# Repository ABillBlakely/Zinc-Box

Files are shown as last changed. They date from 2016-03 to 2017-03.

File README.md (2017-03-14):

# The Zinc Box

### The feature complete RIAA preamp.
#### A Cal Poly AES club project.

## Introduction.

The Zinc Box is an RIAA phono preamp meant to be a simple, high performance preamp for my personal use. The V1.0 was developed solely by myself and was lacking in some of the performance metrics. A new version is being developed within the CPSLO AES club to improve the features and performance of the Zinc Box.

In this repository you will find:
- KiCad contains the project files for schematic capture and PCB creation. In this folder you will also find the Gerber files used for PCB production.
- LTspice folder contains the files used for simulation and testing of project designs.
- Main directory has the current schematic, some reports, and this readme.

## Performance of V1
V1 offered up some pretty decent performance, but has its issues as well. For a more thorough look at performance, check [Performance V1.0.md](Performance V1.0.md).

- Freq Response within +/- 2 dB of ideal across the audio spectrum.
- Channel matching within +/- 0.25 dB.
- THD < 0.05%
- IMD < 0.08%

## Goals
For the second version, subject to change as project is established:
- Match ideal freq response to +/- 0.1dB.
- Lower power supply noise (120 Hz < -90 dB).
- Greatly improved enclosure design, appearance.
- Adjustable input loading.
- THD < 0.005% @ 1 kHz, -3dB output level.
- THD+N < 0.05% @ 1kHz, -3dB output level.
- IMD < 0.05% ITU-R, 13 + 14 kHz 1:1 ratio.

## Updates

#### 2017-3-24 Meeting
We discussed power supply design, and probably tried to cover too many topics in not enough depth. The quick recap:

- The objective of a power supply is to provide stable, constant voltage at the right voltage for the circuit. We know our circuit consists of two op amps so we can figure that we need positive and negative supplies, a total voltage of 20 to 30 volts, and current requirements in the 10's of mA.
- Ripple is the AC noise present on what should be a clean DC supply. V1.0 of the project has problems with power supply noise, so reducing this is a priority.
- An AC voltage must be rectified. The two main types are half-wave and full wave rectification. Full wave wave doubles the ripple frequency while reducing the ripple voltage (both good things) at the expense of requiring 4x the parts count of half wave (or a dedicated IC). 
- An RC filter can reduce ripple, but current will cause a voltage drop across the resistor, and at some point capacitors become physically large and/or expensive, and this limits how effective the filter can be.
- Linear regulators are cheap and easy ways to get a specific voltage output. They come in fixed and variable forms, and usually have around 60 dB (thats a reduction by a factor of 1000) of ripple rejection. 

I am asking that you download the LTSpice folder from up above and install [LTSpice](http://www.linear.com/designtools/software/#LTspice). Ive set up a starting point in 'power supply.asc' from which I would like you to adjust C1, C2, and R1 and try to find a combination that keeps ripple less than 30 uV peak to peak. If you have trouble running the sim, make sure that the two MC78XX files are in the same directory as 'power supply.asc'.

When you have some values that work, go on digikey, mouser or similar and see if you can find the parts available at a reasonable cost. Caps will likely need to be Aluminum electrolytic and should be rated for 50V or higher. 

You may wish to modify the circuit for full wave rectification or make other improvements, any and all improvements are welcome, you can also try simulating a negative regulator using the MC7915. I've added some resources down below specific to power supplies. 

The next official meeting will be the first week of the spring quarter, so there is no rush to get this done during finals week. Questions are welcome in the GroupMe, and let me know if you need to be added to that.

#### Upcoming Meeting 2017-3-10
The next meeting of the Zinc Box preamp project will be Friday, March 10 at 3:00 in the controls lab (20-112).

For this meeting we will be discussing power supply requirements and the basics of power supply design. This meeting will transition out of the workshop style of th first meeting and into having you all doing the hands on design work.

#### 2017-2-24 Meeting
The first meeting held established some of the background of audio testing and measurement.

- I highly recommend you get [ARTA](http://artalabs.hr/), the user manual is pretty good at guiding you through the setup and measurement techniques.
- [Audio Specifications](http://www.rane.com/note145.html) from Rane Audio is a great, succinct, resource for some more detail on the measurements we performed. It also may give you ideas for additional measurements we should make.
- We established some of the goals which are updated in the __Goals__ section above.
- (UPDATE: In room 126.) Next meeting will be Thursday, March 2. We will be performing measurements a little more methodically to produce a new performance report.

## References and Resources
- [LM317]() is a common adjustable regulator, this datasheet has lots of example circuits and aplications worth looking at.
- [MC78XX](http://www.onsemi.com/pub/Collateral/MC7800-D.PDF) is a common fixed positive voltage regulator, the MC79XX are the associated negative voltage regulators.
- [Small, Low Current Power Supplies](http://sound.whsites.net/articles/power-supplies2.htm) from Elliot sound products. This is the second time I've linked to this site, there is lots of good info and example projects here.
- [App note 140, Basic Concepts of Linear Regulator and Switching
Mode Power Supplies](http://cds.linear.com/docs/en/application-note/AN140fa.pdf) from Linear Technology covers some info on when to use linear regulator vs a switching regulator.

- [RIAA Equalization](https://en.wikipedia.org/wiki/RIAA_equalization) from wikipedia for what the RIAA curve is and the history behind the standard.
- [Audio Specifications](http://www.rane.com/note145.html) from Rane Audio for the what and why of audio measurements.
- [ARTA](http://artalabs.hr/) for performing measurements.
- [High-Performance Audio Applications of the LM833](http://www.ti.com/lit/an/snoa586d/snoa586d.pdf) from Texas instruments will be a major reference for design of the filter.
- [Magnetic Phono Pickup Cartridges](http://sound.whsites.net/articles/cartridge-loading.html) from Elliot Sound Products, a discussion on input loading for phono preamps.

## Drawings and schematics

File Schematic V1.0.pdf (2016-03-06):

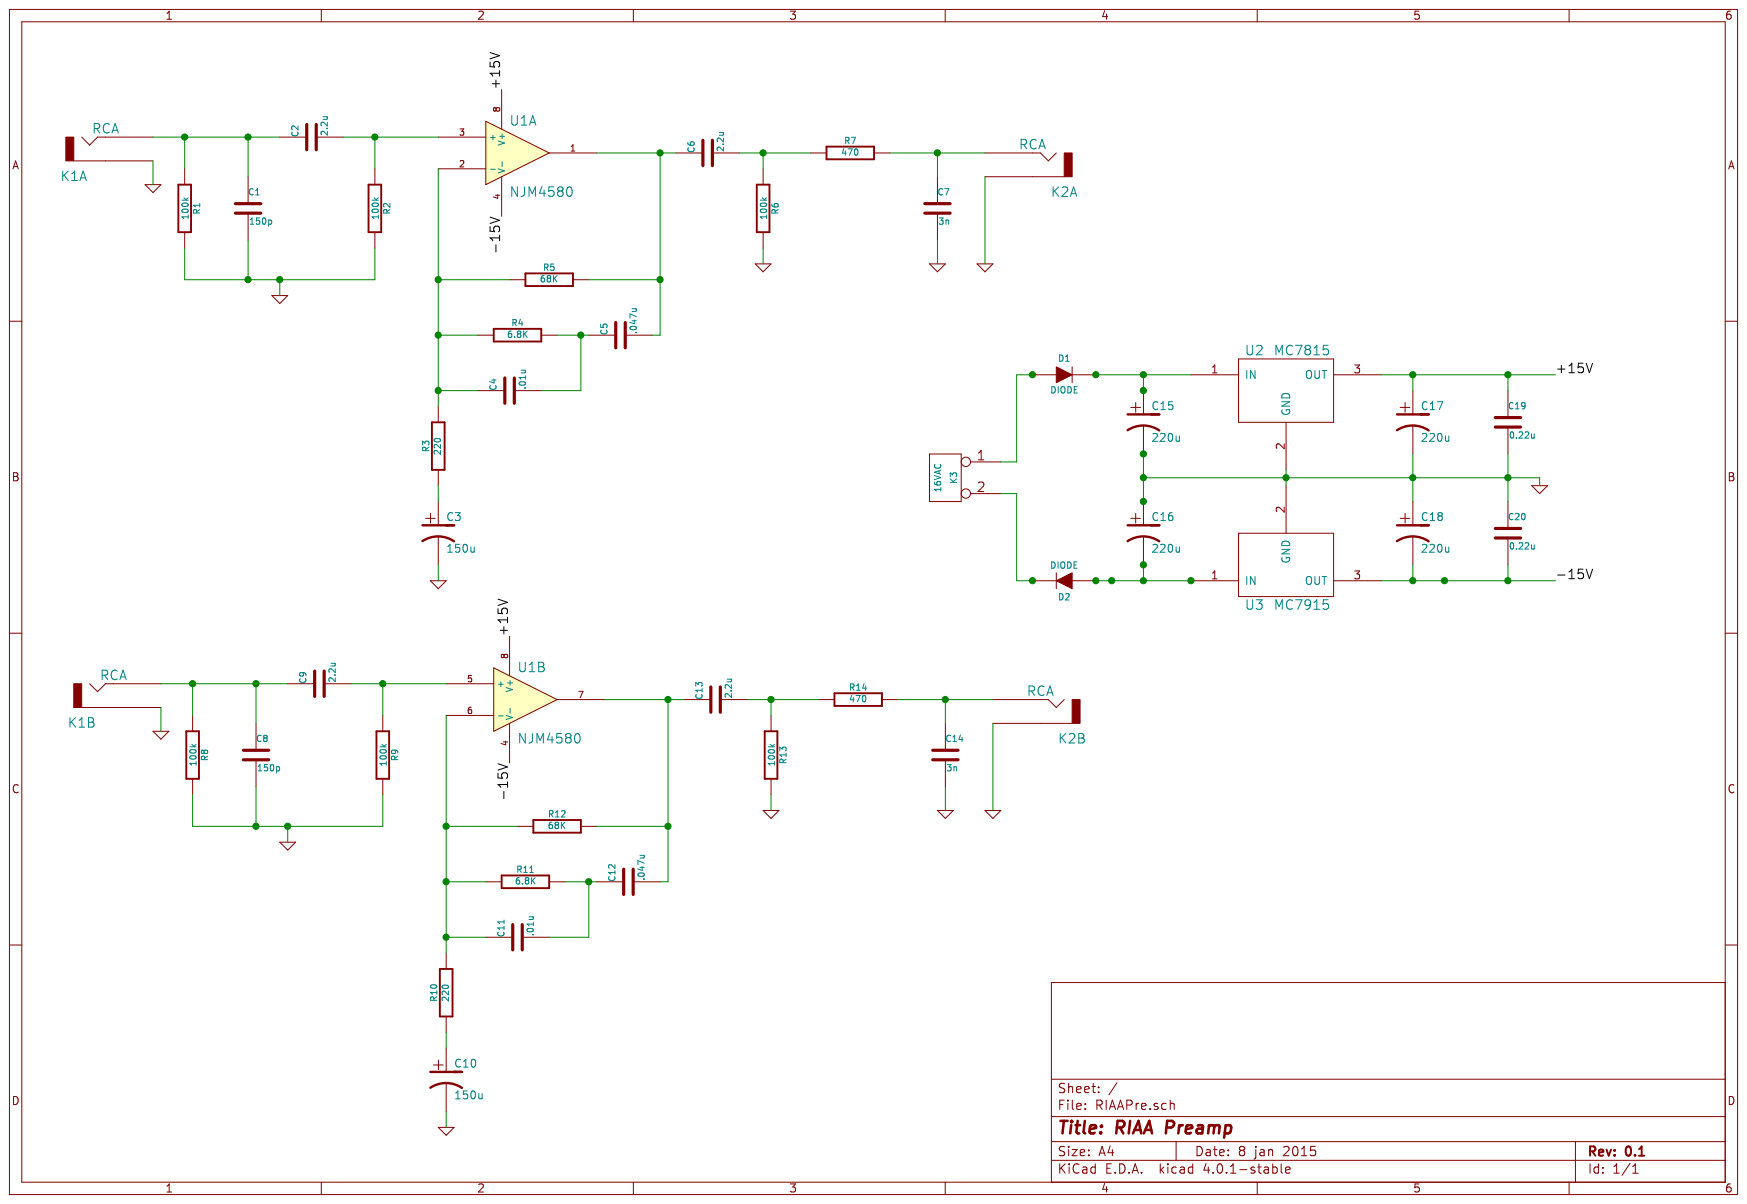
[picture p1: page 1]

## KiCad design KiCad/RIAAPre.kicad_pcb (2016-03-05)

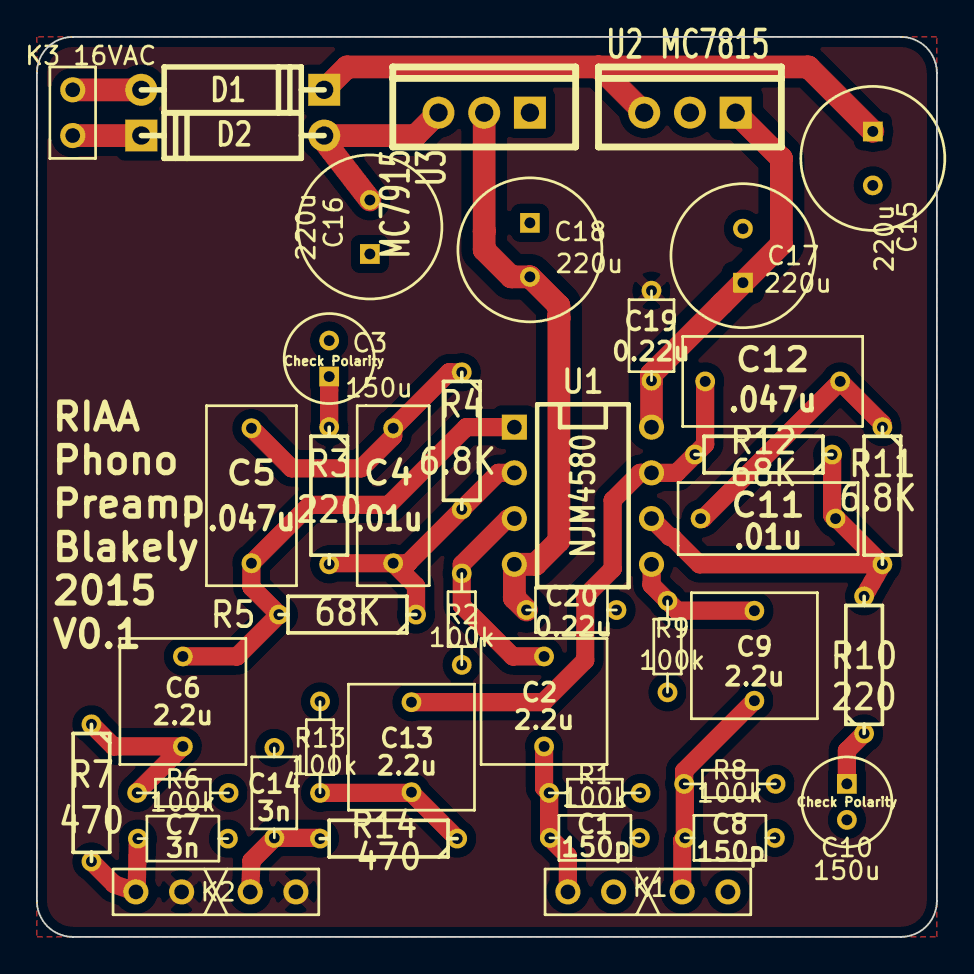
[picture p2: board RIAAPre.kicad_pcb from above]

Board: 2 copper layers, 50.0 x 50.0 mm, 42 parts (0 on the bottom side), 23 nets.

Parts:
C1, C8: 150p; Cap_4.0x2.5_5.0x0.55
C2, C6, C9, C13: 2.2u; Cap_7.2x7.2_5.0x0.55
C3, C10: 150u; Cap_elec_5.0D_2.0x0.55
C4, C11: .01u; Cap_10x4_7.5x0.5
C5, C12: .047u; Cap_10x5.0_7.5x0.5
C7, C14: 3n; Cap_4.0x2.5_5.0x0.55
C15, C16, C17, C18: 220u; Cap_elec_8.0D_3.5x0.55
C19, C20: 0.22u; Cap_4.0x2.5_5.0x0.55
D1, D2: DIODE; D4
K1, K2: RCA; header4_gap
K3: 16VAC; header2
R1, R2, R6, R8, R9, R13: 100k; R_3.0x1.5_5.0x0.55
R3, R10: 220; R_6.5x2.0_7.5x0.55
R4, R11: 6.8K; R_6.5x2.0_7.5x0.55
R5, R12: 68K; R_6.5x2.0_7.5x0.55
R7, R14: 470; R_6.5x2.0_7.5x0.55
U1: NJM4580; DIP-8__300
U2: MC7815; TO220_VERT
U3: MC7915; TO220_VERT

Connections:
/+15V: C17.1, C19.1, U1.8, U2.3
/-15V: C18.2, C20.2, U1.4, U3.2
GND: C1.2, C3.2, C7.2, C8.2, C10.2, C14.2, C15.2, C16.1, C17.2, C18.1, C19.2, C20.1, K1.2, K1.4, K2.2, K2.4, R1.2, R2.2, R6.2, R8.2, R9.2, R13.2, U2.2
unnamed: C1.1, C2.1, K1.1, R1.1
unnamed: C3.1, R3.1
unnamed: C10.1, R10.1
unnamed: C6.2, R6.1, R7.1
unnamed: C12.2, C13.1, R12.2, U1.7
unnamed: C4.2, C5.1, R4.1
unnamed: C7.1, K2.1, R7.2
unnamed: C5.2, C6.1, R5.2, U1.1
unnamed: C4.1, R3.2, R4.2, R5.1, U1.2
unnamed: C2.2, R2.1, U1.3
unnamed: C16.2, D2.1, U3.1
unnamed: C15.1, D1.2, U2.1
unnamed: D2.2, K3.2
unnamed: C8.1, C9.1, K1.3, R8.1
unnamed: C11.2, C12.1, R11.1
unnamed: C11.1, R10.2, R11.2, R12.1, U1.6
unnamed: C13.2, R13.1, R14.1
unnamed: D1.1, K3.1
unnamed: C14.1, K2.3, R14.2
unnamed: C9.2, R9.1, U1.5

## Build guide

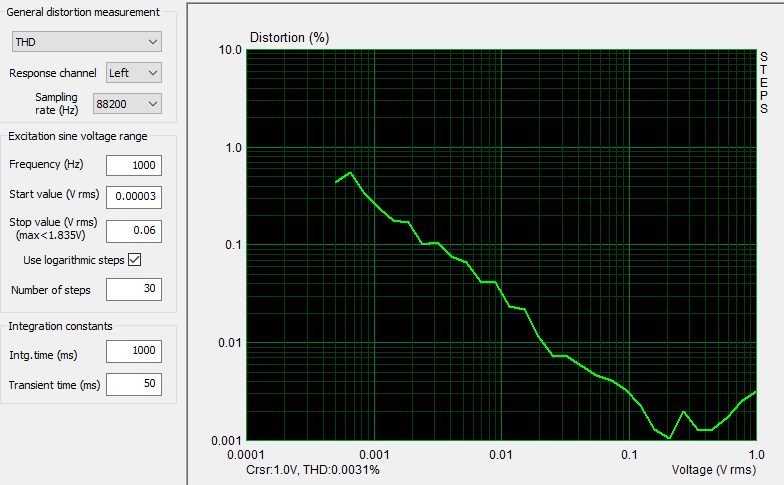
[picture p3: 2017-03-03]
Performance/figures/steps_thd_vs_amplitude.PNG

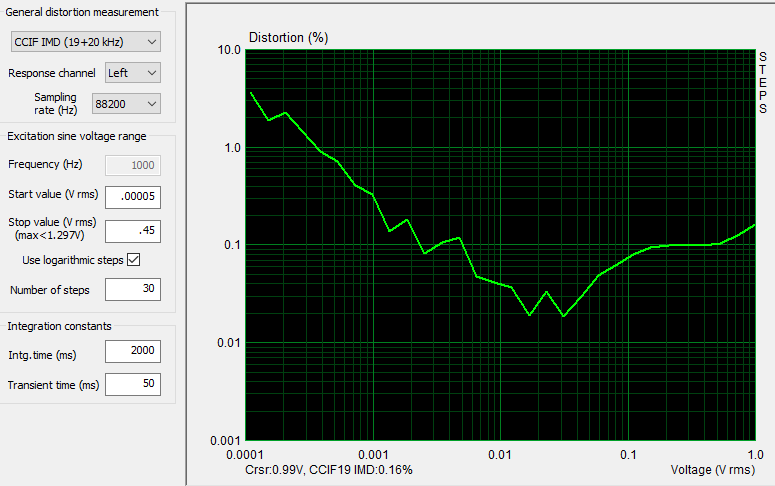
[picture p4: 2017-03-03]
Performance/figures/steps_IMD_vs_amplitude.PNG

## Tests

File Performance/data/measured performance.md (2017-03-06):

# Recorded data from 2017-3-1

## Conditions
88.2 kHz sample rate, 16384 samples, kaiser 7 window, using 100 averages

## Distortion

| Freq (Hz) | Level (dB) | THD (%) | THD+N (%) |
|---|---|---|---|
| 100 | -3.0 |  0.0099 | 0.055 |
| 1000 | -3.3 |  0.0034 | 0.067 |
| 10000 | -2.9 | 0.025 | 0.073 |

| Freqs  (kHz) | Level (dB) | Magnitude ratio | IMD (%) | standard |
|---|---|---|---|---|
| 19/20 | -3.0 | 1:1 | 0.062 | ITU-R |

## Noise

SNR = -67.0 dB re 0 dB, 44 kHz BW.

The noise figure is dominated by the power line noise, with a peak at 60 Hz of -68.54 dB.
No additional filter was used to limit bandwidth, but the low signal level causes the noise above 20 kHz to be negligible, so the value does not significantly improve by limiting bandwidth.

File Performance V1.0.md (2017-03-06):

# RIAA Phono Preamp
## V1.0 Characteristics and Performance.
To characterize the performance of the preamp tests were performed using the [ARTA](http://www.artalabs.hr/) software package. This summary of results is divided into frequency response and distortion.

## Frequency Response.
The frequency response was measured using ARTA, and the data was compared against the ideal response and against an LTSpice simulation of the signal chain. A comparison between the right and left channel was also performed. All values were normalized at 1 kHz to make comparison consistent.

### Overall Response.
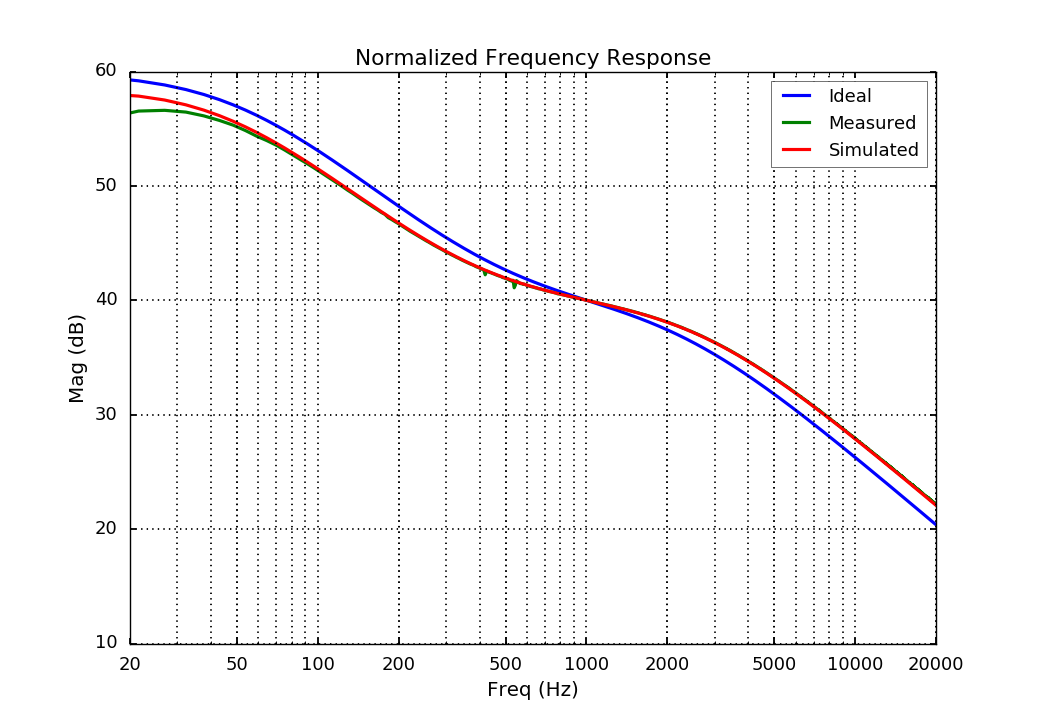
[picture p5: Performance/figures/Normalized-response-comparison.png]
Frequency Response

*Figure 1: Results of frequency measurement.*

The measured response matches the LTspice simulation so closely that it's data is almost obscured entirely. There is some obvious error when compared with the ideal response. This is one of the goals of version 2. Knowing that the simulation can be trusted to match closely with real world performance should make the job of choosing better component values easier.

### Response Error.
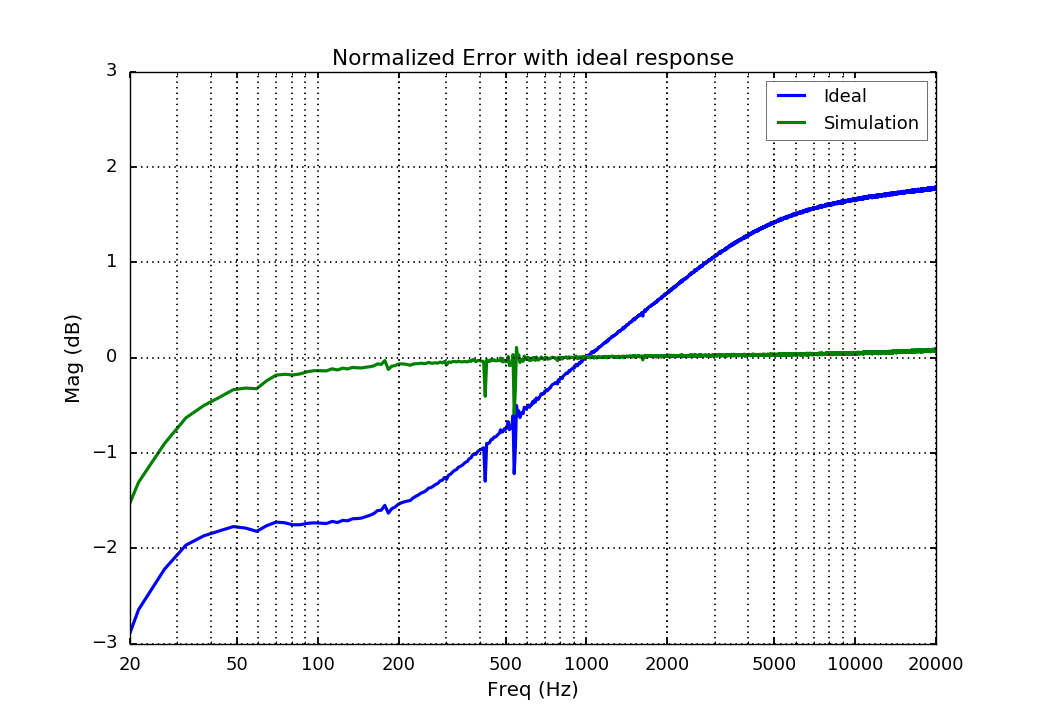
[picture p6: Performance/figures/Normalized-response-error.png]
Frequency Error

*Figure 2: Relative frequency response.*

Figure 2 shows the difference from the measured response to simulated (blue) and the ideal (red). This graph also quantifies what figure 1 had shown before. less than 0.5 dB difference from 20 Hz to 20 kHz for the simulation is very good. The ideal response is not so good, at around 1.5 db too low at low frequencies and almost 2 dB high at high frequencies. This is almost certainly audible difference.

### Channel Matching.
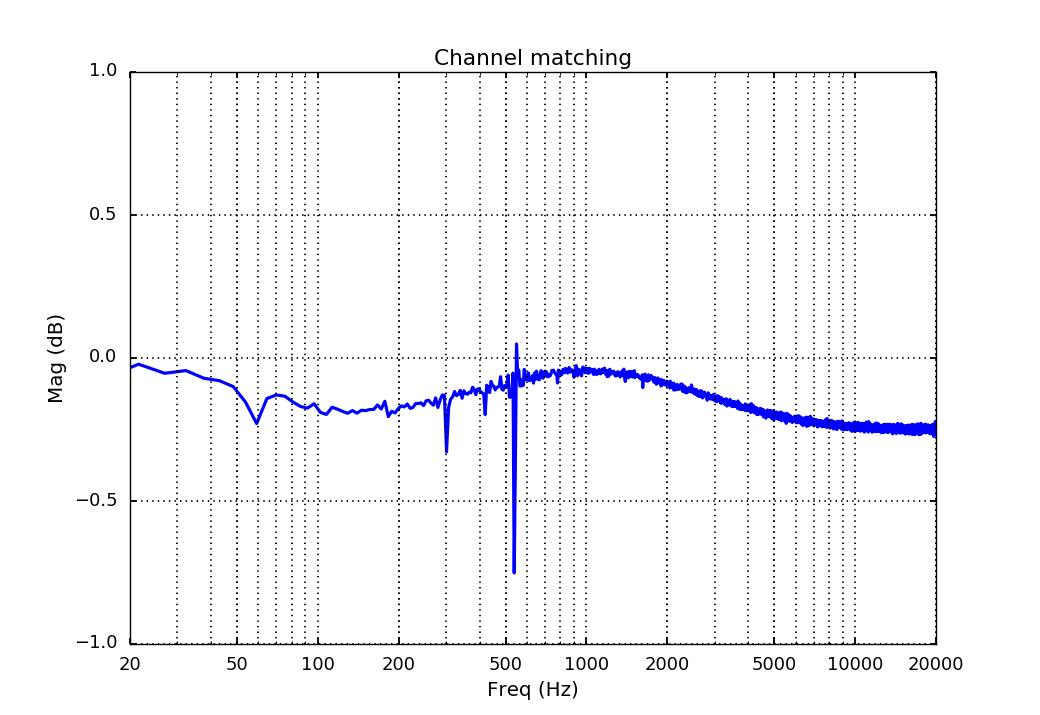
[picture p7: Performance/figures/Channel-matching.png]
Channel Matching

*Figure 3: Difference between left and right channels.*

## Distortion.
Three types of distortion were measured for these tests. THD (*Total harmonic distortion*), THD+N (*THD plus noise*), and IMD (*intermodulation distortion*). THD was checked for anomalies using steps to measure across the frequency response as seen in Figure 4. Measured values are taken at specific points to measure relative to correct signal levels. IMD uses the ITU_R standard of 19/20 kHz twin tones at a ratio of 1:1. For more information on audio distortion I recommend starting with [This RANE Audio note](http://www.rane.com/note145.html).

### Harmonic Distortion.

| Freq (Hz) | Level (dB) | THD (%) | THD+N (%) |
|---|---|---|---|
| 100 | -3.0 |  0.0099 | 0.055 |
| 1000 | -3.3 |  0.0034 | 0.067 |
| 10000 | -2.9 | 0.025 | 0.073 |

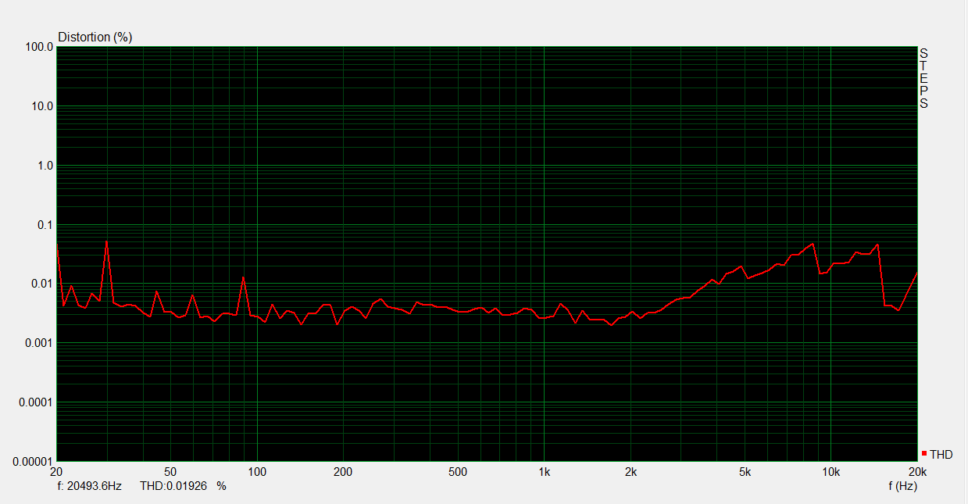
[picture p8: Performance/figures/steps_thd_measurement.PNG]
THD

*Figure 4: THD measured across frequency. Due to the non flat frequency response this does not use the preferred -3dB  signal level so final measurements are performed at just a few values.*

### Intermodulation Distortion.

| Freqs  (kHz) | Level (dB) | Magnitude ratio | IMD (%) | standard |
|---|---|---|---|---|
| 19/20 | -3.0 | 1:1 | 0.062 | ITU-R |

## Noise

The noise level was measured with a 0V input, and taken to be the resulting RMS level.
The noise figure is dominated by the power supply, with the peak -68.5 dB at 60 Hz nearly equal to the the total noise figure.

|Bandwidth |  Noise |
|---|---|
|  44 kHz  | -67.0 dB |

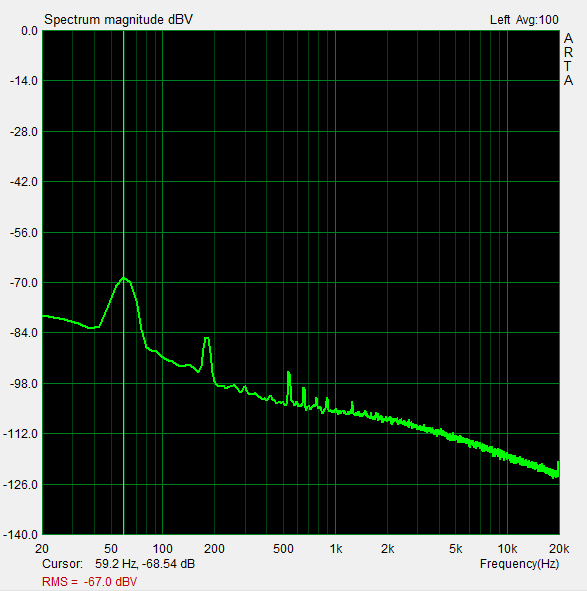
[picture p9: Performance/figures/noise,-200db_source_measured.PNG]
Noise measurement


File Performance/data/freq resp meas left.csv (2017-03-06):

DFT | Frequency Response Magnitude
Numpoints | 8192
SamplingRate(Hz) | 88200.000000
Frequency(Hz) | Magnitude(dB)
5.38 | 30.770721
10.77 | 38.257111
16.15 | 40.328354
21.53 | 40.976395
26.92 | 41.040623
32.30 | 40.886936
37.68 | 40.553440
43.07 | 40.155109
48.45 | 39.743046
53.83 | 39.270168
59.22 | 38.781693
64.60 | 38.395699
69.98 | 37.997639
75.37 | 37.565819
80.75 | 37.133690
86.13 | 36.737030
91.52 | 36.366810
96.90 | 36.001293
102.28 | 35.639320
107.67 | 35.290531
113.05 | 34.979683
118.43 | 34.647652
123.82 | 34.359688
129.20 | 34.056984
134.58 | 33.789696
139.97 | 33.513279
145.35 | 33.250004
150.73 | 33.005577
156.12 | 32.768406
161.50 | 32.544064
166.88 | 32.340866
172.27 | 32.118057
177.65 | 31.949152
183.03 | 31.655115
188.42 | 31.494085
193.80 | 31.312263
199.18 | 31.147558
204.57 | 30.975065
209.95 | 30.803303
215.33 | 30.634579
220.72 | 30.468372
226.10 | 30.327333
231.48 | 30.183762
236.87 | 30.040600
242.25 | 29.907473
247.63 | 29.768116
253.02 | 29.639715
258.40 | 29.524040
263.78 | 29.393332
269.17 | 29.274672
274.55 | 29.163235
279.93 | 29.047365
285.31 | 28.950037
290.70 | 28.836424
296.08 | 28.748104
301.46 | 28.614477
306.85 | 28.548357
312.23 | 28.449314
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

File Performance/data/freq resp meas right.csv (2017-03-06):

DFT | Frequency Response Magnitude
Numpoints | 8192
SamplingRate(Hz) | 88200.000000
Frequency(Hz) | Magnitude(dB)
5.38 | 30.907204
10.77 | 38.319626
16.15 | 40.399536
21.53 | 40.999760
26.92 | 41.095837
32.30 | 40.932625
37.68 | 40.625999
43.07 | 40.236282
48.45 | 39.844730
53.83 | 39.426208
59.22 | 39.012779
64.60 | 38.539608
69.98 | 38.128647
75.37 | 37.701015
80.75 | 37.289074
86.13 | 36.908127
91.52 | 36.543869
96.90 | 36.162857
102.28 | 35.831287
107.67 | 35.489574
113.05 | 35.153728
118.43 | 34.828468
123.82 | 34.548309
129.20 | 34.251965
134.58 | 33.975430
139.97 | 33.707958
145.35 | 33.434383
150.73 | 33.191441
156.12 | 32.950230
161.50 | 32.725571
166.88 | 32.506733
172.27 | 32.298187
177.65 | 32.102291
183.03 | 31.861780
188.42 | 31.682217
193.80 | 31.505985
199.18 | 31.326790
204.57 | 31.144430
209.95 | 30.975952
215.33 | 30.796980
220.72 | 30.646324
226.10 | 30.501589
231.48 | 30.344776
236.87 | 30.201342
242.25 | 30.066160
247.63 | 29.936235
253.02 | 29.791191
258.40 | 29.673403
263.78 | 29.552334
269.17 | 29.441416
274.55 | 29.304573
279.93 | 29.222033
285.31 | 29.098925
290.70 | 28.967655
296.08 | 28.880138
301.46 | 28.944553
306.85 | 28.722952
312.23 | 28.595222
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

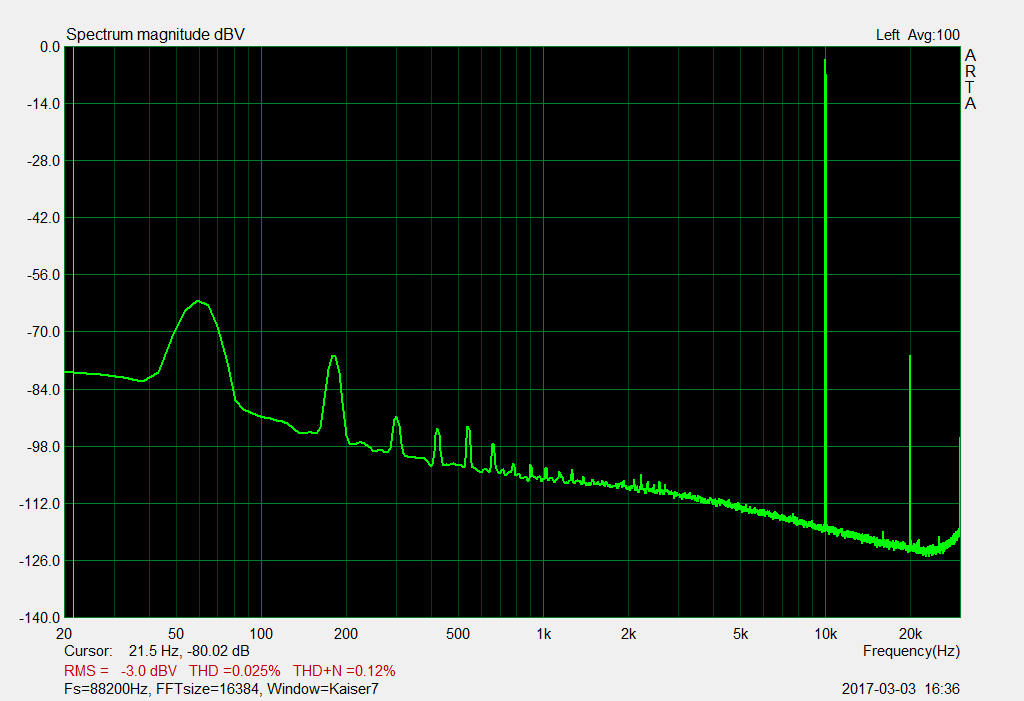
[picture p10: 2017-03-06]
Performance/figures/thd_10kHz.png

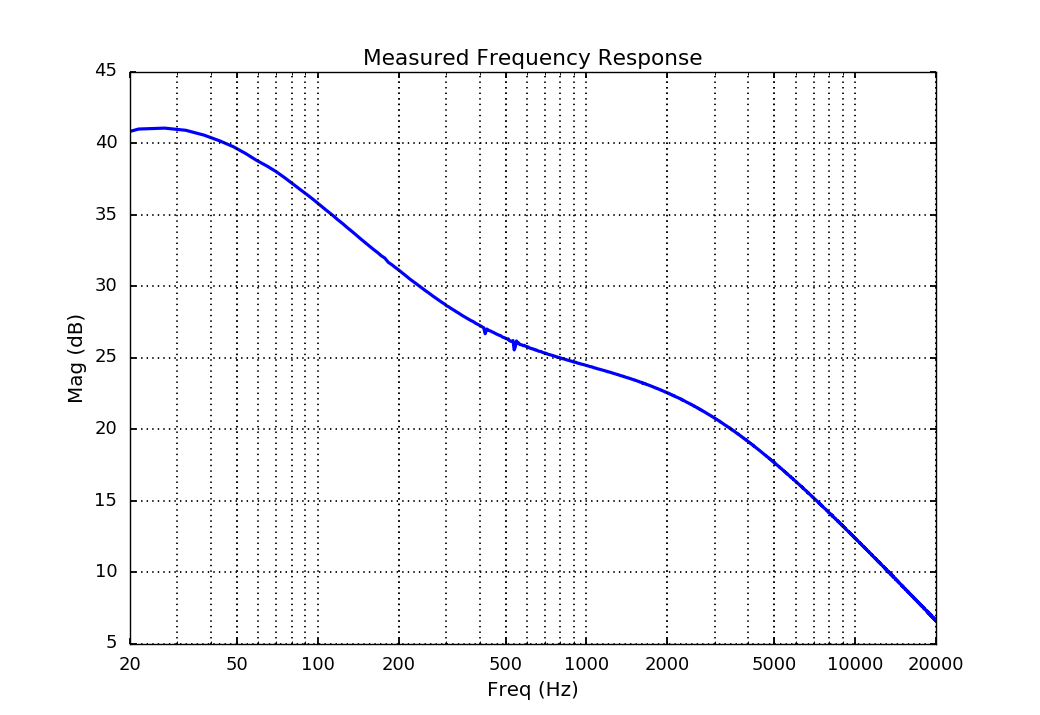
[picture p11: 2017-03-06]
Performance/figures/Frequency-response-comparison.png

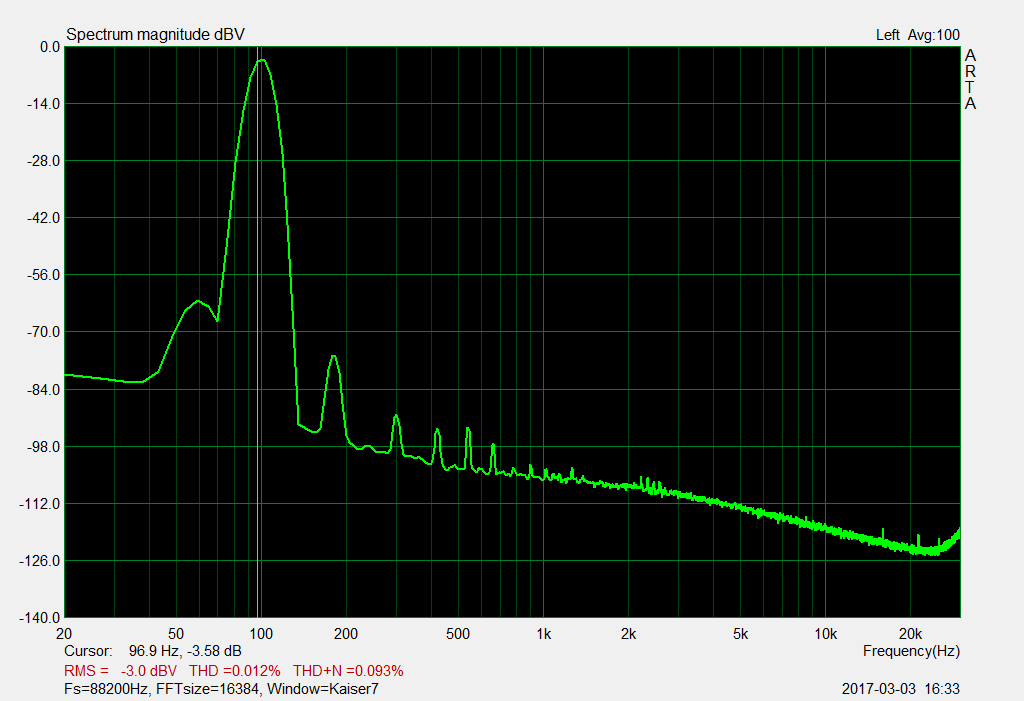
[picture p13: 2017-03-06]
Performance/figures/thd_100Hz.png

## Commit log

2016-03-05 Initial Commit. V1.0 of the Riaa Preamp.
    [RIAAPre-B_Cu.gbl, RIAAPre-B_Mask.gbs, RIAAPre-B_SilkS.gbo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]
2016-03-06 Directory cleanup and ignore additions.
    [RIAAPre.sch]
2016-03-06 Added performance folder with figures and data
    [Right channel measured frequency response.csv, freq resp meas left.csv]
2016-03-06 Add v1.0 schematic in pdf
2017-03-03 Remove old response files.
    [Right channel measured frequency response.csv]
2017-03-06 Clean and fix so script works with current data.
2017-03-06 Add current measurment data and figures, update spice sim to match.
    [freq resp meas left.csv, freq resp meas right.csv]
2017-03-06 Create an ideal transfer curve circuit and symbol in LTSpice.
2017-03-06 Add ideal response to simulation for comparison, Change C7 to match schematic value.
2017-03-10 Update power supply design with models of MC78XX.
2017-03-12 Include Spice Models of MC78XX and MC79XX regulators.
2017-03-14 Fix the power sim so it uses the correct library.
2017-03-14 Include details of 3-24 meeting and current tasks.
